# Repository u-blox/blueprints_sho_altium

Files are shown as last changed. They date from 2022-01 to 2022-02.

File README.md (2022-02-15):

# u-blox blueprints

This repository contains u-blox blueprints (reference designs) created using
Altium Designer.

There are two sets of files maintained within the blueprints_sho_altium
repository:
1. Designs
2. Chamber scans

## Designs
The designs folder contain the schematic and PCB design files for u-blox blueprint
reference designs. See the README.md within the Designs folder for the most
current list.

## Chamber scans
The chamber scan folders contain far field 2D and 3D radiation pattern scans
for a blueprint or EVK. See the README.md within the Chamber scans folder for
viewing instructions.

The folder structure is arranged like this:
```
/--+---Designs (Altium design files)
   |   |
   |   +--- Bxxx
   |   +--- Byyy
   |   +--- Bzzz
   |   ...
   |
   +---Chamber scans
       |
       +--- Bxxx
       +--- Byyy
       +--- Bzzz
       +--- EVK-abcd

... where "Bxxx", "Byyy", etc. are the blueprint numbers and "EVK-abcd" is the 
EVK board name.
```

---------------------------------------------------------------------------------
Copyright © u-blox

u-blox reserves all rights in this deliverable (documentation, software, etc.,
hereafter “Deliverable”).

u-blox grants you the right to use, copy, modify and distribute the Deliverable
provided hereunder for any purpose without fee.

THIS DELIVERABLE IS BEING PROVIDED "AS IS", WITHOUT ANY EXPRESS OR IMPLIED
WARRANTY. IN PARTICULAR, NEITHER THE AUTHOR NOR U-BLOX MAKES ANY REPRESENTATION
OR WARRANTY OF ANY KIND CONCERNING THE MERCHANTABILITY OF THIS DELIVERABLE
OR ITS FITNESS FOR ANY PARTICULAR PURPOSE.

In case you provide us a feedback or make a contribution in the form of a
further development of the Deliverable (“Contribution”), u-blox will have the
same rights as granted to you, namely to use, copy, modify and distribute the
Contribution provided to us for any purpose without fee.

---------------------------------------------------------------------------------

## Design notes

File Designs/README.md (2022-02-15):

# u-blox blueprint design files.

The designs contained within this repository are u-blox blueprints created with
Altium Designer. These are example designs suitable for a starting point in an
end-product. These are not full EVKs, rather an example of a feature used in a
project.

The following blueprints are maintained here:

|Blueprint number | Description |
|---|---|
| B212 | RF range test board, 40x22 plane, ANNA-B112 in corner position |
| B213 | RF range test board, 22x20 plane, ANNA-B112 in corner position |
| B214 | RF range test board, 40x22 plane, ANNA-B112 in edge position |
| B215 | RF range test board, 22x20 plane, ANNA-B112 in edge position |
| B216 | RF range test board, 40x22 plane, BMD-300, BMD-330, or BMD-360 |
| B217 | RF range test board, 22x20 plane, BMD-300, BMD-330, or BMD-360 |
| B218 | RF range test board, 40x22 plane, BMD-340 |
| B219 | RF range test board, 22x20 plane, BMD-340 |
| B220 | RF range test board, 40x22 plane, BMD-350 |
| B221 | RF range test board, 22x20 plane, BMD-350 |
| B222 | RF range test board, 40x22 plane, BMD-380 |
| B223 | RF range test board, 22x20 plane, BMD-380 |
| B224 | RF range test board, 40x22 plane, NINA-B112 |
| B225 | RF range test board, 22x20 plane, NINA-B112 |
| B226 | RF range test board, 40x22 plane, NINA-B302 |
| B227 | RF range test board, 22x20 plane, NINA-B302 |
| B228 | RF range test board, 40x22 plane, NINA-B306 |
| B229 | RF range test board, 22x20 plane, NINA-B306 |
| B230 | RF range test board, 40x22 plane, NINA-B406 |
| B231 | RF range test board, 22x20 plane, NINA-B406 |
| B232 | RF range test board, 40x22 plane, NORA-B106 |
| B233 | RF range test board, 22x20 plane, NORA-B106 |

Directory structure
---------------------------------------------------------------------------------
```
/-- Bxxx_name
    |
    +--- BOM
    |    |
    |    +--- Bxxx_name.xlsx = Bill of Materials output from Altium (optional)
    |
    +--- Documentation
    |    |
    |    +--- Bxxx_name.PDF = schematic in PDF format
    |
    +--- Fabrication
    |    |
    |    +--- Gerber = folder with Gerber file outputs
    |    +--- NC Drill = folder with drill data
    |    +--- ODB = folder with ODB file outputs
    |    +--- Pick Place = folder with pick and place tool outputs
    |    +--- Test Points = folder with test point outputs
    |
    +--- PCB
    |    |
    |    +--- Bxxx.PcbDoc = Altium PCB layout design file
    |
    +--- Settings
    |    |
    |    +--- Outputs.OutJob = Product output file definitions (BOM, PDF, fabrication, etc)
    |
    +--- Source
    |    |
    |    +--- Bxxx_.SchDoc = Altium schematic design file
    |
    +--- Bxxx_name.IntLib = integrated library of components used within the design
    +--- Bxxx_name.PrjPcb = Altium project file
    +--- Bxxx_name.PrjPcbVariants = Build variant definitions (optional)

```
The main files to view the design in Altium are the .PrjPcb, .SchDoc, .PcbDoc, and .IntLib.
B216 and B217 each have three variants, one each for BMD-300, BMD-330, and BMD-360 modules.
Other boards only have one variant, so the ".PcbDocVariants" file may not be present.

The other files are generated by Altium, and are provided here for user convenience.

---------------------------------------------------------------------------------
Copyright © u-blox

u-blox reserves all rights in this deliverable (documentation, software, etc.,
hereafter “Deliverable”).

u-blox grants you the right to use, copy, modify and distribute the Deliverable
provided hereunder for any purpose without fee.

THIS DELIVERABLE IS BEING PROVIDED "AS IS", WITHOUT ANY EXPRESS OR IMPLIED
WARRANTY. IN PARTICULAR, NEITHER THE AUTHOR NOR U-BLOX MAKES ANY REPRESENTATION
OR WARRANTY OF ANY KIND CONCERNING THE MERCHANTABILITY OF THIS DELIVERABLE
OR ITS FITNESS FOR ANY PARTICULAR PURPOSE.

In case you provide us a feedback or make a contribution in the form of a
further development of the Deliverable (“Contribution”), u-blox will have the
same rights as granted to you, namely to use, copy, modify and distribute the
Contribution provided to us for any purpose without fee.

---------------------------------------------------------------------------------

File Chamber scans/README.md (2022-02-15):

# EVK and blueprint - RF chamber scans

RF chamber scans are performed selected bluprint designs and EVKs. Blueprints
B212 through B233 correspond to "mid-size" (40 x 22 mm ground plane) and "small-
size" (22 x 20 mm ground plane) carrier boards for the module noted in the
filename and table below. In addition to the two blueprints for each module, 
EVKs were also scanned:

|Blueprint number | Description |
|---|---|
| B212 | RF range test board, 40x22 plane, ANNA-B112 in corner position |
| B213 | RF range test board, 22x20 plane, ANNA-B112 in corner position |
| B214 | RF range test board, 40x22 plane, ANNA-B112 in edge position |
| B215 | RF range test board, 22x20 plane, ANNA-B112 in edge position |
| B216 | RF range test board, 40x22 plane, BMD-300, BMD-330, or BMD-360 |
| B217 | RF range test board, 22x20 plane, BMD-300, BMD-330, or BMD-360 |
| B218 | RF range test board, 40x22 plane, BMD-340 |
| B219 | RF range test board, 22x20 plane, BMD-340 |
| B220 | RF range test board, 40x22 plane, BMD-350 |
| B221 | RF range test board, 22x20 plane, BMD-350 |
| B222 | RF range test board, 40x22 plane, BMD-380 |
| B223 | RF range test board, 22x20 plane, BMD-380 |
| B224 | RF range test board, 40x22 plane, NINA-B112 |
| B225 | RF range test board, 22x20 plane, NINA-B112 |
| B226 | RF range test board, 40x22 plane, NINA-B302 |
| B227 | RF range test board, 22x20 plane, NINA-B302 |
| B228 | RF range test board, 40x22 plane, NINA-B306 |
| B229 | RF range test board, 22x20 plane, NINA-B306 |
| B230 | RF range test board, 40x22 plane, NINA-B406 |
| B231 | RF range test board, 22x20 plane, NINA-B406 |
| B232 | RF range test board, 40x22 plane, NORA-B106 |
| B233 | RF range test board, 22x20 plane, NORA-B106 |
| EVK-ANNA-B112C  | ANNA-B112 EVK, SIP placed in the corner of the PCB |
| EVK-ANNA-B112E  | ANNA-B112 EVK, SIP placed along the PCB edge |
| EVK-ANNA-B112U  | ANNA-B112 EVK, external 3.2 dBi whip antenna |
| EVK-BMD-300-EVAL| BMD-300 EVK, PCB trace antenna |
| EVK-BMD-301-EVAL| BMD-301 EVK, external 5 dBi whip antenna |
| EVK-BMD-330-EVAL| BMD-330 EVK, PCB trace antenna |
| EVK-BMD-340-EVAL| BMD-340 EVK, PCB trace antenna |
| EVK-BMD-341-EVAL| BMD-341 EVK, external 3 dBi whip antenna |
| EVK-BMD-345-EVAL| BMD-345 EVK, external 3 dBi whip antenna |
| EVK-BMD-350-EVAL| BMD-350 EVK, PCB chip antenna |
| EVK-BMD-360-EVAL| BMD-360 EVK, PCB trace antenna |
| EVK-BMD-380-EVAL| BMD-380 EVK, PCB chip antenna | 
| EVK-NINA-B111 | NINA-B111, external 3.2 dBi whip antenna |
| EVK-NINA-B112 | NINA-B112, PIFA antenna |
| EVK-NINA-B301 | NINA-B301, external 3.2 dBi whip antenna |
| EVK-NINA-B302 | NINA-B302, PIFA antenna |
| EVK-NINA-B306 | NINA-B306, PCB trace antenna |
| EVK-NINA-B400 | NINA-B400, external 3.2 dBi whip antenna |
| EVK-NINA-B406 | NINA-B406, PCB trace antenna |
| EVK-NORA-B106 | NORA-B106, PCB trace antenna |

Unzip the selected file to a folder. 
Each folder contains four files and four similarly named sub-folders:
<board>-2d.html and <board>-2d-files folder
<board>-3d-xy.html and <board>-3d-xy-files folder
<board>-3d-xz.html and <board>-3d-xz-files folder
<board>-3d-yz.html and <board>-3d-yz-files folder

Open the HTML file in a web browser to view the plot.

The three 3D plots display the same data. The only difference is the initial 
view according to the plane in the filename. For example, <board>-3d-xy.html
shows the plot looking at the X-Y plane with the Z-axis "out of the page".
Hovering over a point on the 3D plot will show the measured EIRP, azimuth,
and elevation. Click and drag the plot to rotate it.

The 2D plots display slices of the 3D plot at the X-Y, X-Z, and Y-Z planes.
Hovering over the plot will show the EIRP, angle, and an indication of 
whether the horizontal or vertical antenna axis was used, or a combined 
measurement of the two.

Scans for all blueprints are in 15 degree azimuth and elevation increments. 
Additional scans for EVK-NINA-B302, EVK-NINA-B306, EVK-NINA-B406, 
EVK-BMD-340-EVAL, and EVK-BMD-380-EVAL, denoted by "-5deg" added to the filename

---------------------------------------------------------------------------------
Copyright © u-blox

u-blox reserves all rights in this deliverable (documentation, software, etc.,
hereafter “Deliverable”).

u-blox grants you the right to use, copy, modify and distribute the Deliverable
provided hereunder for any purpose without fee.

THIS DELIVERABLE IS BEING PROVIDED "AS IS", WITHOUT ANY EXPRESS OR IMPLIED
WARRANTY. IN PARTICULAR, NEITHER THE AUTHOR NOR U-BLOX MAKES ANY REPRESENTATION
OR WARRANTY OF ANY KIND CONCERNING THE MERCHANTABILITY OF THIS DELIVERABLE
OR ITS FITNESS FOR ANY PARTICULAR PURPOSE.

In case you provide us a feedback or make a contribution in the form of a
further development of the Deliverable (“Contribution”), u-blox will have the
same rights as granted to you, namely to use, copy, modify and distribute the
Contribution provided to us for any purpose without fee.

---------------------------------------------------------------------------------

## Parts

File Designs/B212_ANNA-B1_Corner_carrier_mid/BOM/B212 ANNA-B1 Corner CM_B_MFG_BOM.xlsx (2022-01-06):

Description | Designator | Footprint | Quantity | Manufacturer | Manufacturer P/N | Manufacturer Part Number
Chip Capacitor, 10 pF, +/- 5%, 50 V, 0402 (1005 Metric) | C1, C2 | CAPC1005X55X25ML05T05 | 2
CAP CER X5R 0402 | C3 | Cap 0402 | 1 | Samsung Electro-Mechanics | CL05A104KP5NNN
Diode, ESD9B, 3.3V, ST5G, SOD-923 | D1, D2 | SOD-923 | 2 | ON Semiconductor | ESD9B3.3ST5G
LED, RGB Diffused SMT, PLCC4 4 Pin | D3 | 4-PLCC | 1 | Cree, Inc. | CLMVB-FKA-CFHEHLCBB7a363
THT Angled Pin Header WR-PHD, Pitch 2.54 mm, Single Row, 8 pins | P1 | 61300811021 | 1 | Wurth Electronics |  | 61300811021
Resistor, 499ohm, 1%, 1/16W, 0402 | R1 | RES 0402 HD | 1 | Rohm Semiconductor | MCR01MRTF4990
Resistor, 220ohm, 5%, 1/16W, 0402. | R2, R3 | RES 0402 HD | 2 | Panasonic Electronic Components | ERJ-2GEJ221X
Button, Momentary SPST-NO, 0.05A, 12V, 3mm x 2.5mm | SW1, SW2 | B3U-1000P | 2 | Omron Electronics Inc-EMC Div | B3U-1000P
u-blox ANNA-B112 Bluetooth 5 LE module | U1 | ANNA_LGA52S_650X650 | 1 | u-blox
XTAL, 2Pin, 32.768kHz, 7pF 20ppm | X1 | XTAL_3215 | 1 | Epson | FC-135 32.7680KA-AG3

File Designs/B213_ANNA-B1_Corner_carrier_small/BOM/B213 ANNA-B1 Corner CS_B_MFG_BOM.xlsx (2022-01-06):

Description | Designator | Footprint | Quantity | Manufacturer | Manufacturer P/N | Manufacturer Part Number
Chip Capacitor, 10 pF, +/- 5%, 50 V, 0402 (1005 Metric) | C1, C2 | CAPC1005X55X25ML05T05 | 2
Diode, ESD9B, 3.3V, ST5G, SOD-923 | D1, D2 | SOD-923 | 2 | ON Semiconductor | ESD9B3.3ST5G
LED, RGB Diffused SMT, PLCC4 4 Pin | D3 | 4-PLCC | 1 | Cree, Inc. | CLMVB-FKA-CFHEHLCBB7a363
Chip Inductor, 56 nH, +/-5%, 390 mA, -55 to 125 degC, 0603 (1608 Metric), RoHS, Tape and Reel | L1, L2 | INDC1608X100X30LL20T10 | 2 | Murata
1.5M screw mounting hole, plated | MH1, MH2 | MH_M1.5 | 2
THT Angled Pin Header WR-PHD, Pitch 2.54 mm, Single Row, 8 pins | P1 | 61300811021 | 1 | Wurth Elektronik |  | 61300811021
CON PADS FOR CBL PLUG-OF-NAILS 6-PIN NO LEGS | P2 | TC2030-IDC-NL | 1 | TAG Connect | TC2030-IDC-NL
Resistor, 220ohm, 5%, 1/16W, 0402. | R4 | RES 0402 HD | 1
Resistor, 220ohm, 5%, 1/16W, 0402. | R5, R6, R7, R8, R9, R10, R11, R12, R13, R14, R15, R17 | RES 0402 HD | 12 | [NoParam], Panasonic Electronic Components | [NoParam], ERJ-2GEJ221X
Resistor, 499ohm, 1%, 1/16W, 0402 | R16 | RES 0402 HD | 1 | Rohm Semiconductor | MCR01MRTF4990
Button, Momentary SPST-NO, 0.05A, 12V, 3mm x 2.5mm | SW1, SW2 | B3U-1000P | 2 | Omron Electronics Inc-EMC Div | B3U-1000P
u-blox ANNA-B112 Bluetooth 5 LE module | U1 | ANNA_LGA52S_650X650 | 1 | u-blox
XTAL, 2Pin, 32.768kHz, 7pF 20ppm | X1 | XTAL_3215 | 1 | Epson | FC-135 32.7680KA-AG3

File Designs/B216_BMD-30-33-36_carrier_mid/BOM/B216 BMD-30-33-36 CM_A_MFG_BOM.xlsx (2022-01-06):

Description | Designator | Footprint | Quantity | Manufacturer | Manufacturer P/N | Manufacturer Part Number
CAP CER COG 0402 | C1, C2 | Cap 0402 | 2 | Murata Manufacturing Company, Ltd. | GRM1555C1H120KZ01
CAP CER COG 0402 | C3, C4 | Cap 0402 | 2 | Murata Manufacturing Company, Ltd. | GRM1555C1H100CZ01
CAP CER X5R 0402 | C5 | Cap 0402 | 1 | Samsung Electro-Mechanics | CL05A104KP5NNN
LED, RGB Diffused SMT, PLCC4 4 Pin | D1 | 4-PLCC | 1 | Cree, Inc. | CLMVB-FKA-CFHEHLCBB7a363
Diode, ESD9B, 3.3V, ST5G, SOD-923 | D2, D3 | SOD-923 | 2 | ON Semiconductor | ESD9B3.3ST5G
1.5M screw mounting hole, plated | MH1, MH2 | MH_M1.5 | 2
CON PADS FOR CBL PLUG-OF-NAILS 6-PIN NO LEGS | P1 | TC2030-IDC-NL | 1 | TAG Connect | TC2030-IDC-NL
THT Angled Pin Header WR-PHD, Pitch 2.54 mm, Single Row, 8 pins | P2 | 61300811021 | 1 | Wurth Electronics |  | 61300811021
Resistor, 499ohm, 1%, 1/16W, 0402 | R1 | RES 0402 HD | 1 | Rohm Semiconductor | MCR01MRTF4990
Resistor, 220ohm, 5%, 1/16W, 0402. | R2, R3 | RES 0402 HD | 2 | Panasonic Electronic Components | ERJ-2GEJ221X
Button, Momentary SPST-NO, 0.05A, 12V, 3mm x 2.5mm | SW1, SW2 | B3U-1000P | 2 | Omron Electronics Inc-EMC Div | B3U-1000P
u-blox BMD-300 Bluetooth 5 LE module | U1 | BMD_LGA47S_1400X980X190_PCB | 1 | u-blox | BMD-300-A-R
XTAL, 2Pin, 32.768kHz, 7pF 20ppm | X1 | XTAL_3215 | 1 | Epson | FC-135 32.7680KA-AG3

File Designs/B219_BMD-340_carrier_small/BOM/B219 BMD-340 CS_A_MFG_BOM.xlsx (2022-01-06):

Description | Designator | Footprint | Quantity | Manufacturer | Manufacturer P/N | Manufacturer Part Number
CAP CER COG 0402 | C1, C2 | Cap 0402 | 2 | Murata Manufacturing Company, Ltd. | GRM1555C1H100CZ01
CAP CER X5R 0402 | C3, C4 | Cap 0402 | 2 | Samsung Electro-Mechanics | CL05A104KP5NNN
Diode, ESD9B, 3.3V, ST5G, SOD-923 | D1, D2 | SOD-923 | 2 | ON Semiconductor | ESD9B3.3ST5G
LED, RGB Diffused SMT, PLCC4 4 Pin | D3 | 4-PLCC | 1 | Cree, Inc. | CLMVB-FKA-CFHEHLCBB7a363
Chip Inductor, 22 nH, +/-5%, 640 mA, -55 to 125 degC, 0603 (1608 Metric), RoHS, Tape and Reel | L1, L2 | INDC1608X100X30LL20T10 | 2 | Murata
1.5M screw mounting hole, plated | MH1, MH2 | MH_M1.5 | 2
CON PADS FOR CBL PLUG-OF-NAILS 6-PIN NO LEGS | P1 | TC2030-IDC-NL | 1 | TAG Connect | TC2030-IDC-NL
THT Angled Pin Header WR-PHD, Pitch 2.54 mm, Single Row, 8 pins | P2 | 61300811021 | 1 | Wurth Electronics |  | 61300811021
RES THICK FILM CHIP 0402 | R1, R2, R3, R7, R8, R9, R10, R11, R12, R13, R14 | RES 0402 HD | 11 | YAGEO | 2322_705_87221_L
Resistor, 499ohm, 1%, 1/16W, 0402 | R4 | RES 0402 HD | 1 | Rohm Semiconductor | MCR01MRTF4990
Resistor, 220ohm, 5%, 1/16W, 0402. | R5, R6 | RES 0402 HD | 2 | Panasonic Electronic Components | ERJ-2GEJ221X
Button, Momentary SPST-NO, 0.05A, 12V, 3mm x 2.5mm | SW1, SW2 | B3U-1000P | 2 | Omron Electronics Inc-EMC Div | B3U-1000P
u-blox BMD-340 Bluetooth 5 LE, 802.15.4 module | U1 | BMD_LGA68S_1500X1020X190_PCB | 1 | u-blox | BMD-340-A-R
XTAL, 2Pin, 32.768kHz, 7pF 20ppm | X1 | XTAL_3215 | 1 | Epson | FC-135 32.7680KA-AG3

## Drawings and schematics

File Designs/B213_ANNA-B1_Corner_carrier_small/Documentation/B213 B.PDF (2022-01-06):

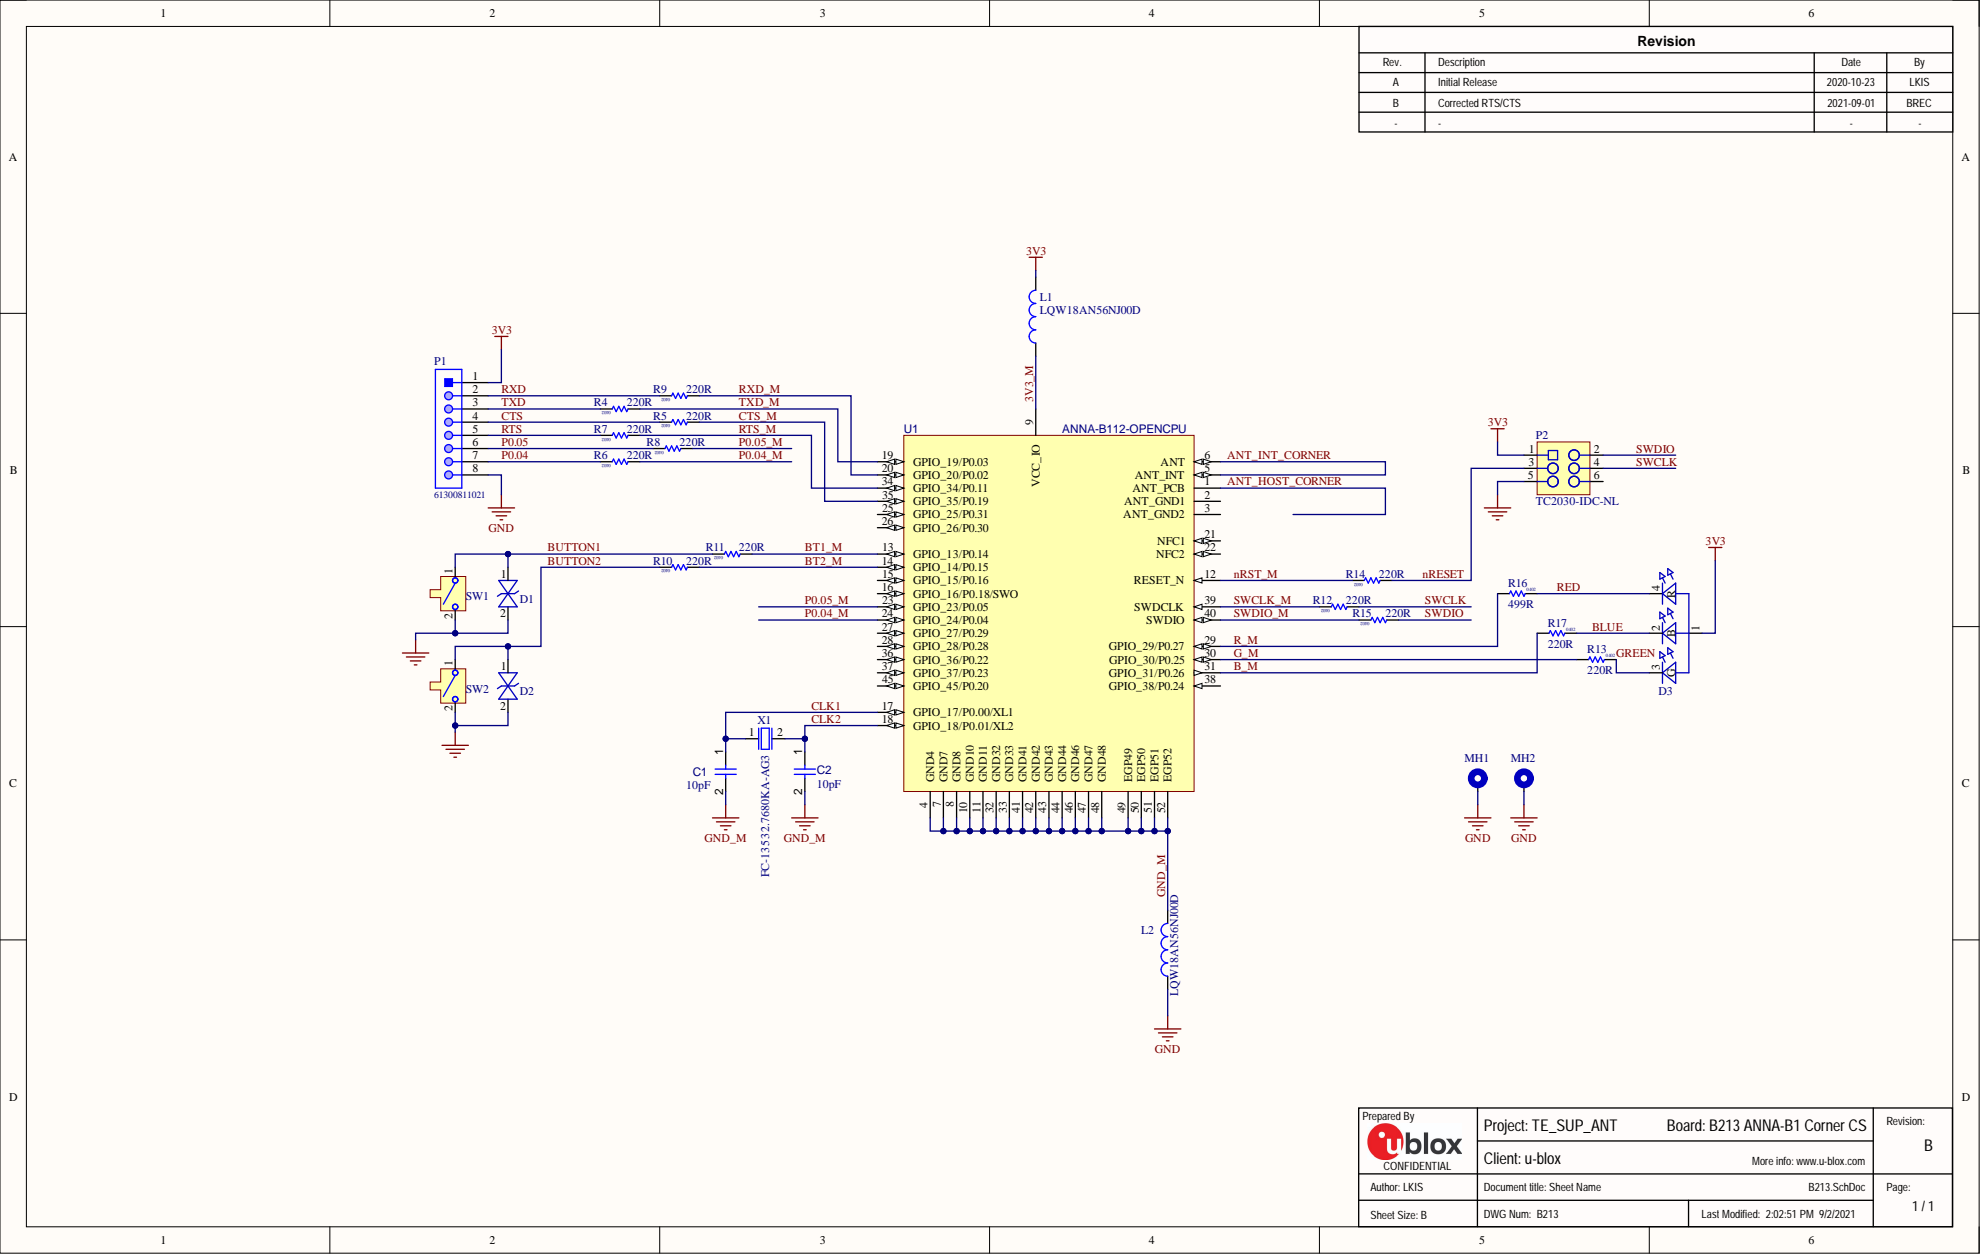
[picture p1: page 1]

Rev. | Description | Date | By
A | Initial Release | 2020-10-23 | LKIS

B | Corrected RTS/CTS | 2021-09-01 | BREC

BUTTON2 R10

P0.05_M | GPIO_16/P0.18/SWO 16 GPIO_15/P0.16 15

GPIO_36/P0.22 36 | G_M
GPIO_37/P0.23 37 | B_M

Board: B213 ANNA-B1 Corner CS

More info: www.u-blox.com

Author: LKIS | Document title: Sheet Name B213.SchDoc | Page: 1 / 1

Sheet Size: B | DWG Num: B213 | Last Modified: 2:02:51 PM 9/2/2021

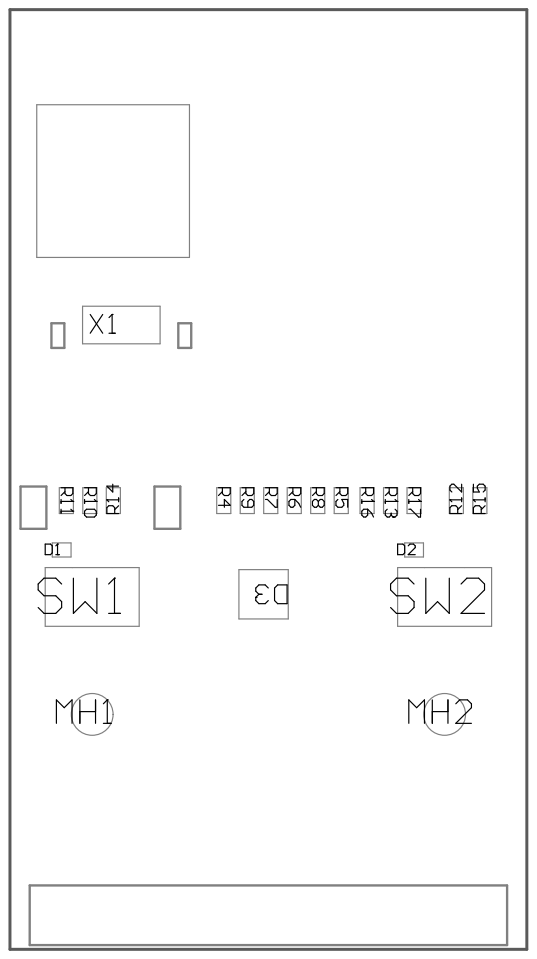
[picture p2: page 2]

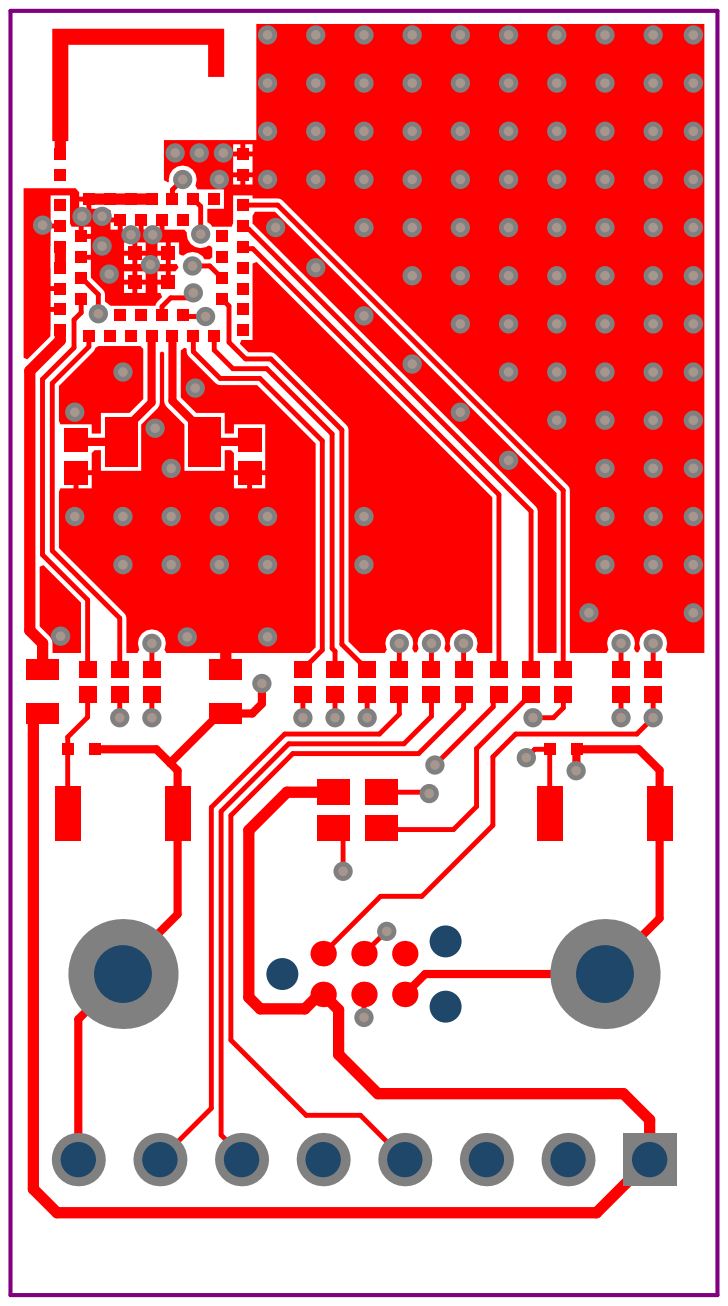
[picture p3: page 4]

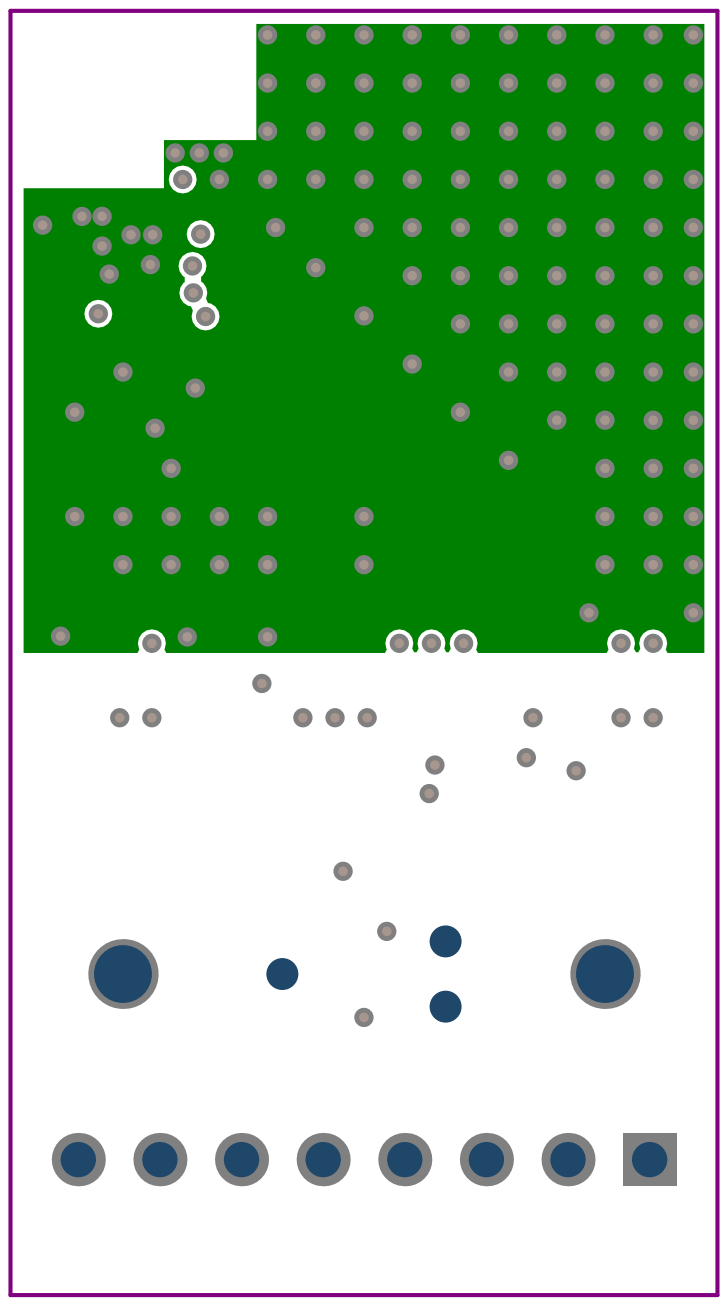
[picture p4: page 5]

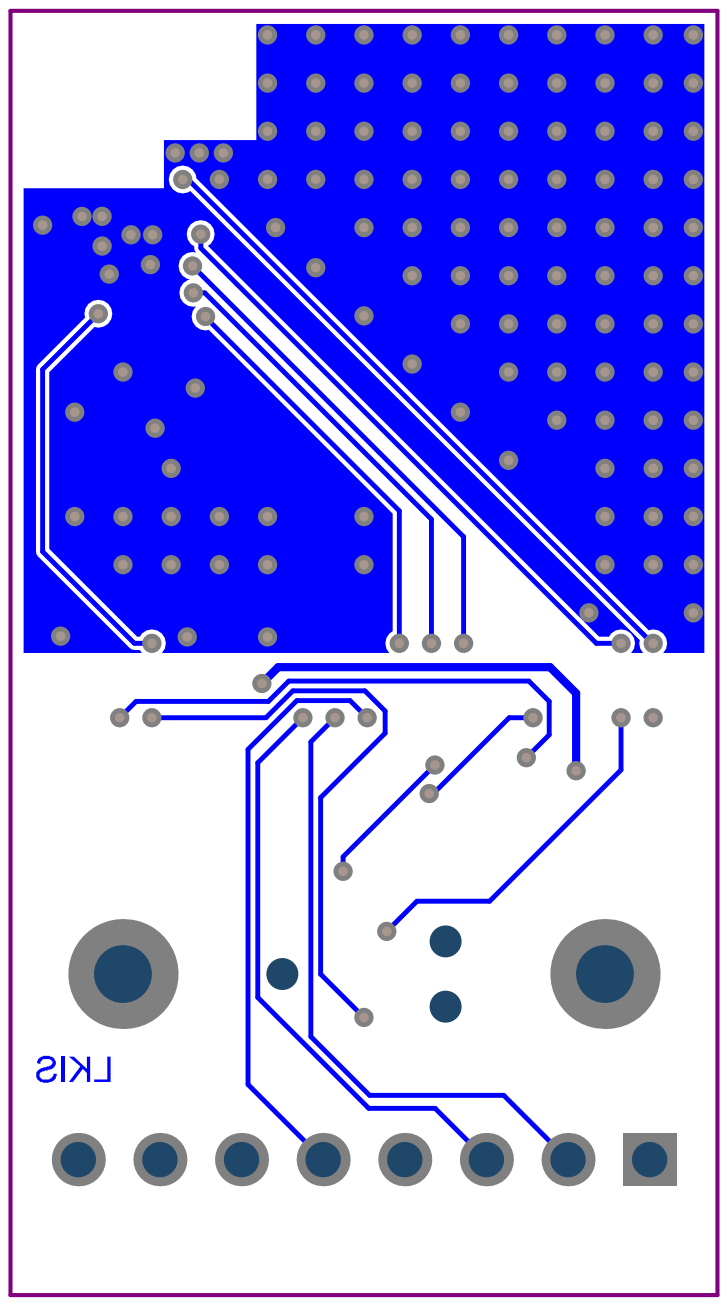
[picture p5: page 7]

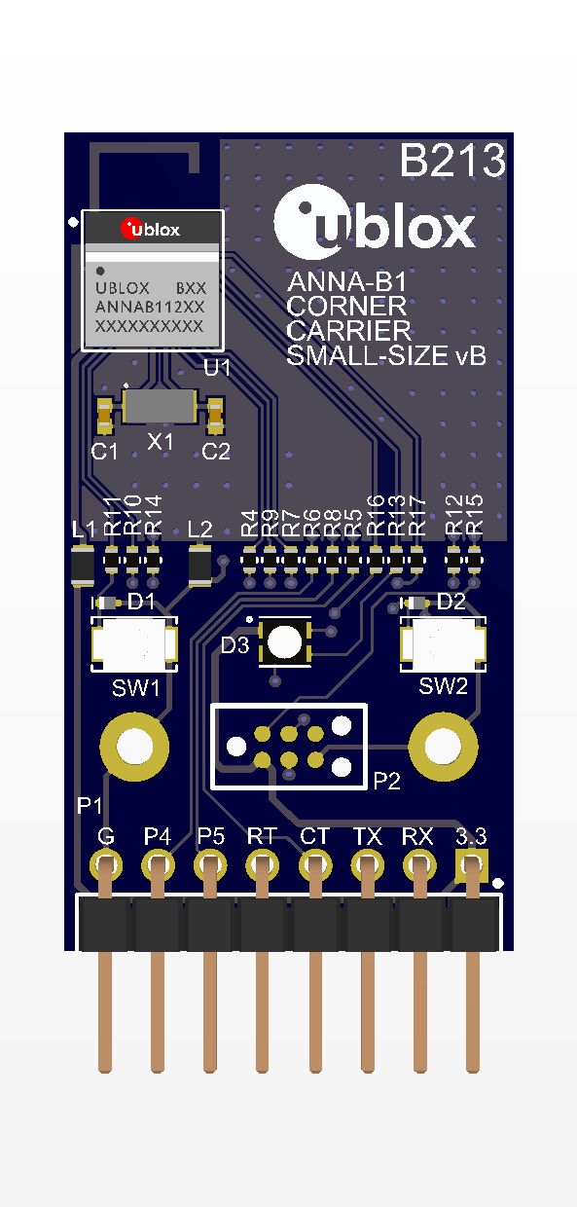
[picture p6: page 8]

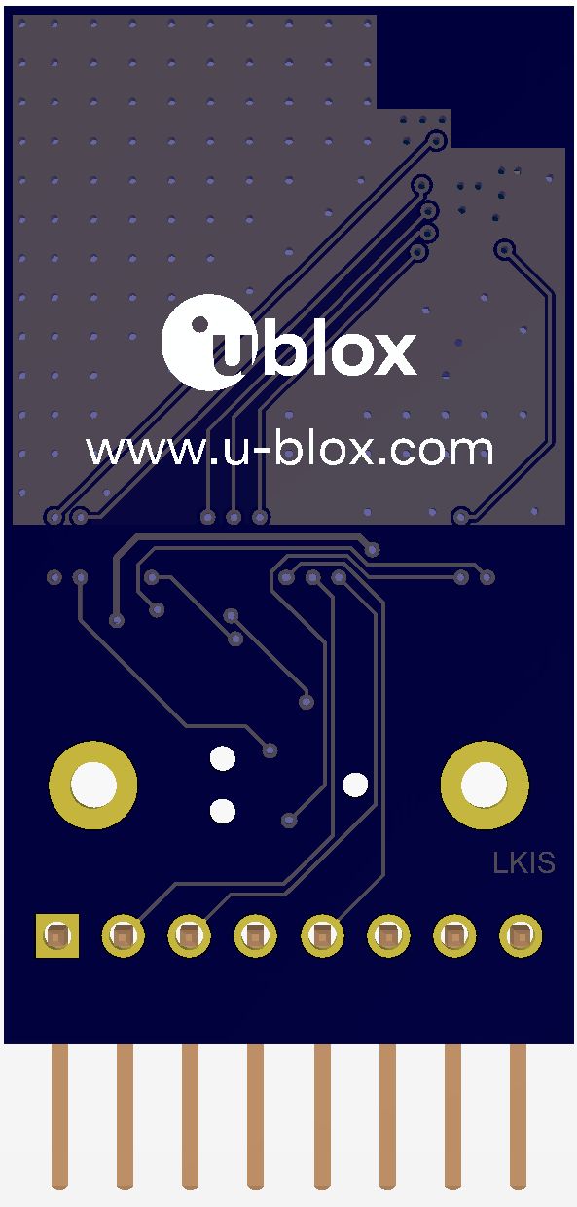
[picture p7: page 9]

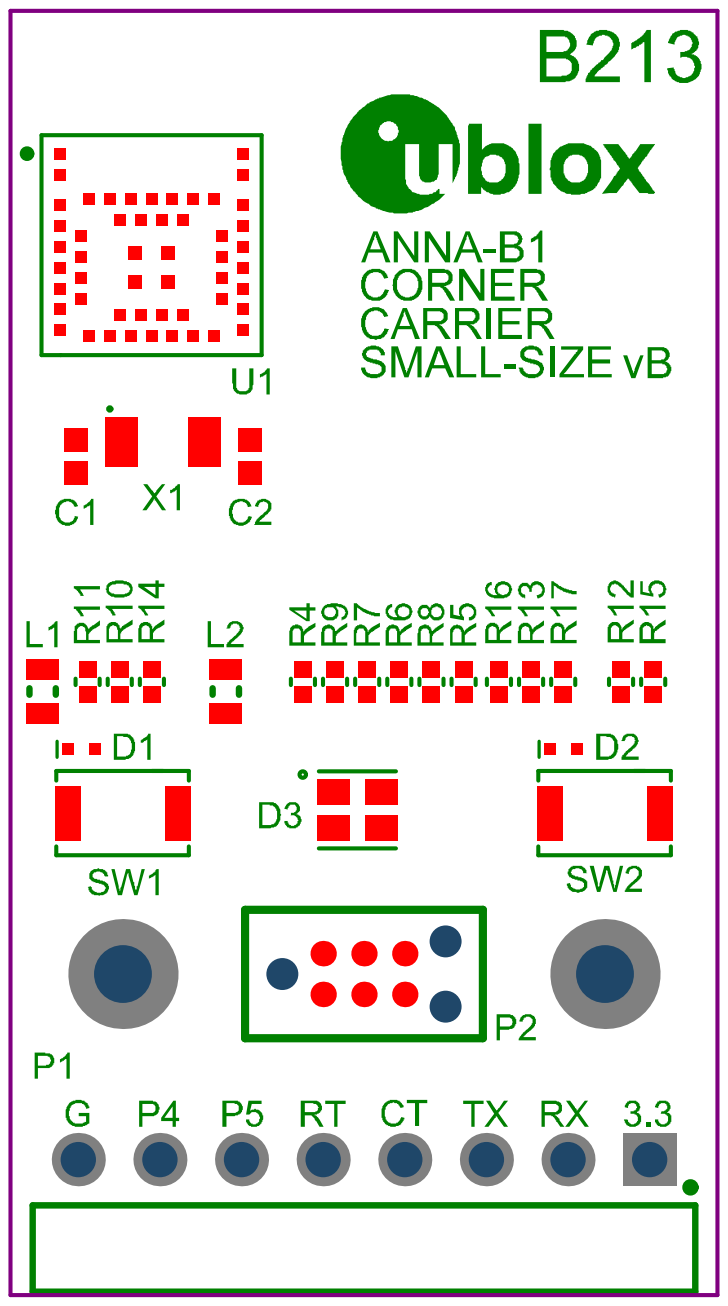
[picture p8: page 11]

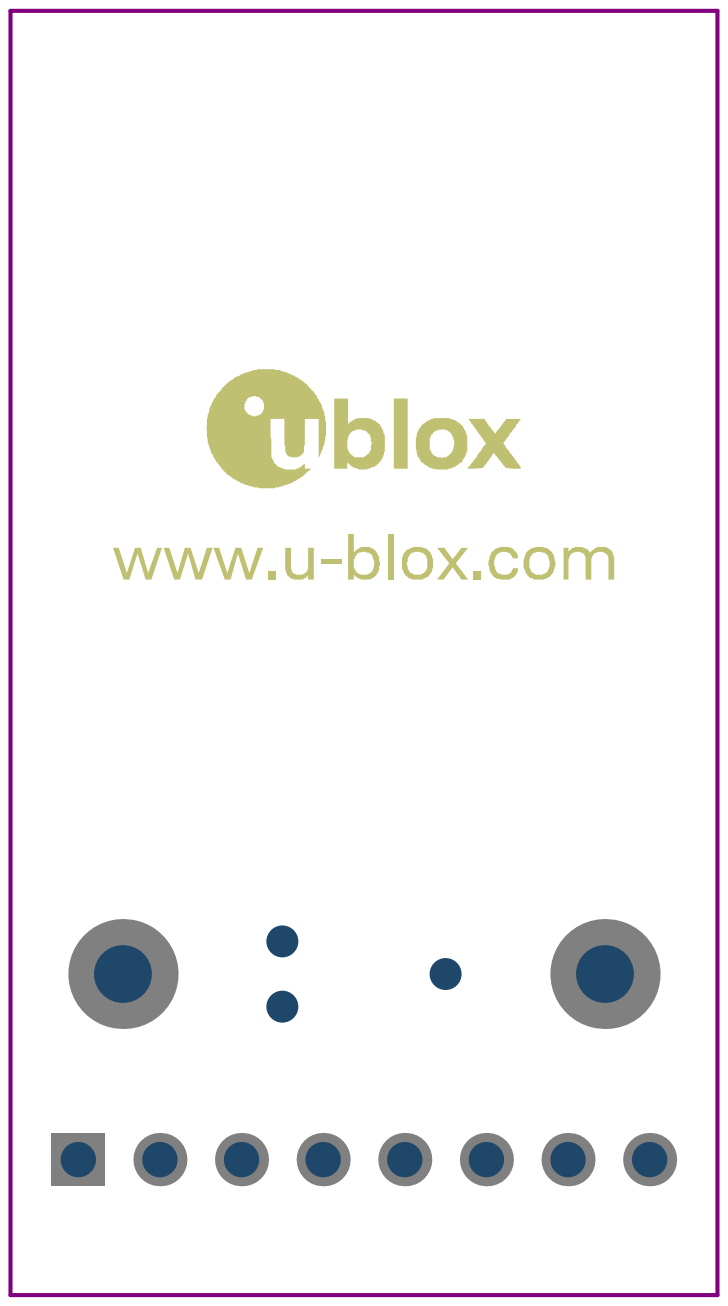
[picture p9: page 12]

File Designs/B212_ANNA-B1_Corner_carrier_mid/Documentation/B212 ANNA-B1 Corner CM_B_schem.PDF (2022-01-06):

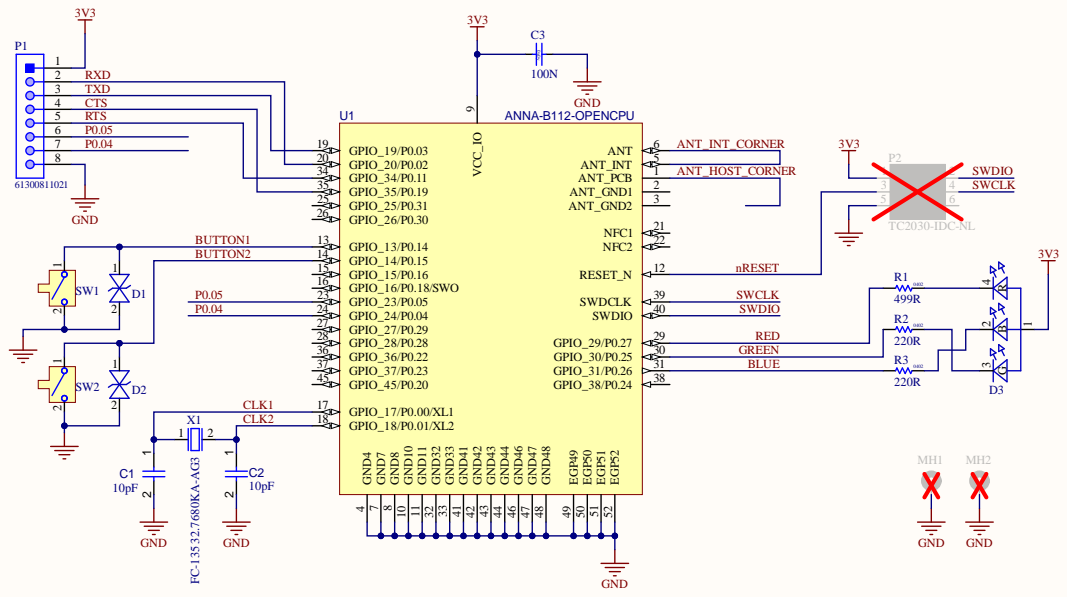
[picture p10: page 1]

Rev. | Description | Date | By
A | Initial Release | 2020-10-23 | LKIS

B | Corrected RTS/CTS | 2021-09-01 | BREC

CT S
RT S

2 0 | | 5
3 4 | | 1 A N T _ H OST _ C O RN

BU T T O N 2 | 1 4 | 1 2
1 5 P0 . 0 5

Board: B212 ANNA-B1 Corner CM

More info: www.u-blox.com

Author: LKIS | Document title: Sheet Name B212.SchDoc | Page: 1 / 1

Sheet Si ze: B | DWG Num: B212 | Last Modified: 10:53:07 AM 9/2/2021

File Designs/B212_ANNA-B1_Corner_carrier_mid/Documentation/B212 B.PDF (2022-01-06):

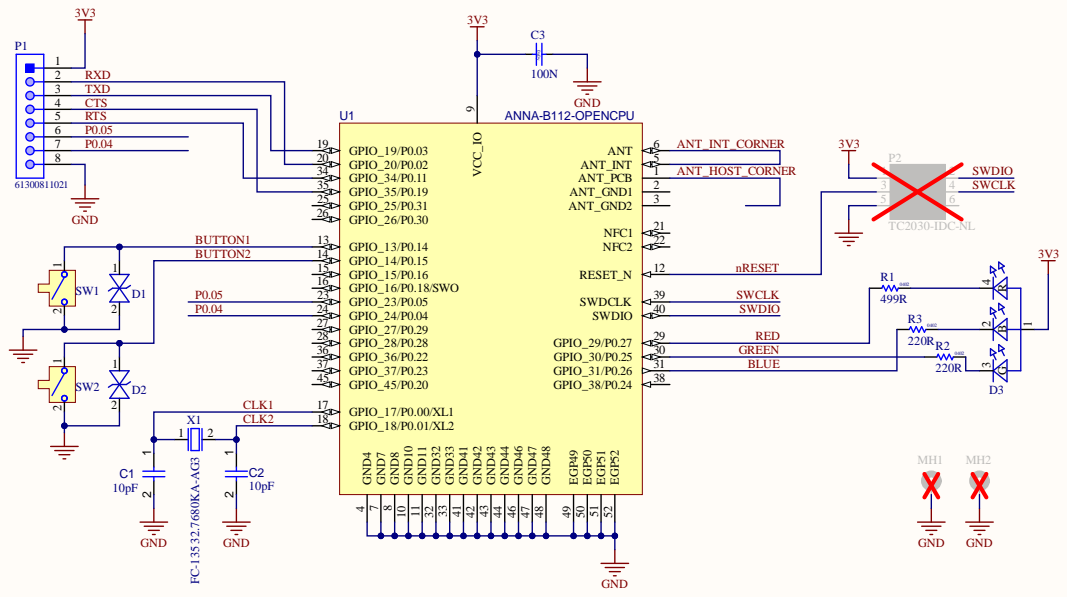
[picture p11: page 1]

Rev . | Des cription | Date | By
A | Initial Releas e | 2020-10-23 | LKIS

B | Corrected RTS/CTS | 2021-09-01 | BREC

CT S
RT S

2 0 | | 5
3 4 | | 1 A N T _ H OST _ C O RN

BU T T O N 2 | 1 4 | 1 2
1 5 P0 . 0 5

Board: B212 ANNA-B1 Corner CM

More info: www.u-blox.com

Author: LKIS | Document title: Sheet Name B212.SchDoc | Page: 1 / 1

Sheet Si ze: B | DWG Num: B212 | Last Modified: 2:02:04 PM 9/2/2021

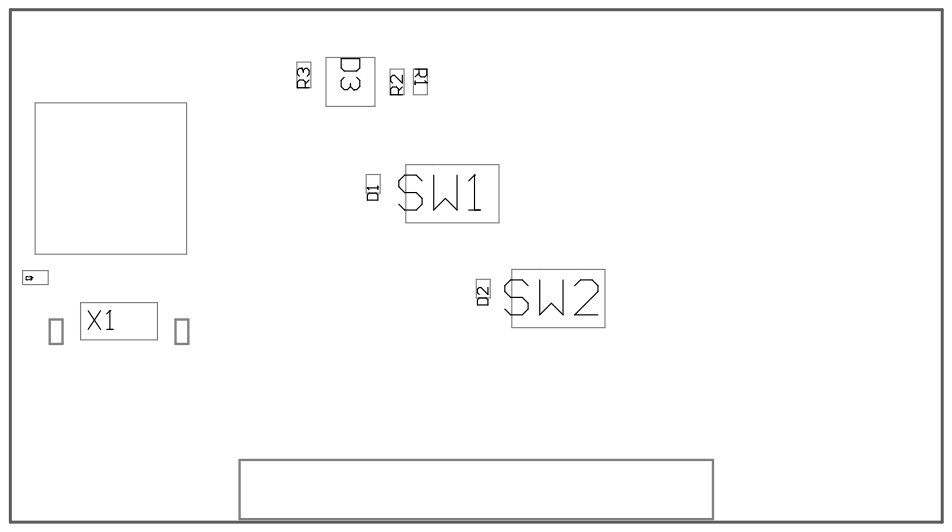
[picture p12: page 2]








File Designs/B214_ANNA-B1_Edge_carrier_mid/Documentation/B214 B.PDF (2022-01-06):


Rev . | Des cription | Date | By
A | Initial Releas e | 2020-10-23 | LKIS

B | Corrected RTS/CTS | 2021-09-01 | BREC

CT S
RT S

2 0 | | 5
3 4 | | 1
3 5 | | 2 3

3 | nRE S E T | 5

BU T T O N 2 | 1 4 | 1 2
1 5 P0 . 0 5

Board: B214 ANNA-B1 Edge CM

More info: www.u-blox.com

Author: LKIS | Document title: Sheet Name B214.SchDoc | Page: 1 / 1

Sheet Si ze: B | DWG Num: B214 | Last Modified: 2:03:26 PM 9/2/2021









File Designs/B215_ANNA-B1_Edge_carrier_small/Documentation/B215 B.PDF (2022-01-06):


Rev. | Description | Date | By
A | Initial Release | 2020-10-23 | LKIS

B | Corrected RTS/CTS | 2021-09-02 | BREC

P0.05_M | GPIO_16/P0.18/SWO 16 GPIO_15/P0.16 15

SWCLK_M 220R 2040 R12 SWCLK SWDIO_M 220R 2040 R15 SWDIO

Board: B215 ANNA-B1 Edge CS

More info: www.u-blox.com

Author: LKIS | Document title: Sheet Name B215.SchDoc | Page: 1 / 1

Sheet Size: B | DWG Num: B215 | Last Modified: 2:03:59 PM 9/2/2021









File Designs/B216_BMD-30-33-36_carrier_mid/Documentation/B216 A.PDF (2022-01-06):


Rev. | Description | Date | By
A | Initial Release | 2020-10-23 | BREC

P0.27 8 | RED

P0.29/AIN5 10 | GREEN
P0.30/AIN6 11 | BLUE

P0.02/AIN0 15 | BUTTON_2

3 | TXD
4 | CTS
5 | RTS
6 | P0.04
7 | P0.03

More info: www.u-blox.com

Author: BREC | Document title: Sheet Name B216.SchDoc | Page: 1 / 1

Sheet Size: B | DWG Num: B216 | Last Modified: 5:29:12 PM 9/2/2021









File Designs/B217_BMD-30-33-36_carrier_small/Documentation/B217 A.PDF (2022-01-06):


Rev. | Description | Date | By
A | Initial Release | 2020-10-23 | BREC

3 | TXD
4 | CTS
5 | RTS
6 | P0.04
7 | P0.03

More info: www.u-blox.com

Author: BREC | Document title: Sheet Name B217.SchDoc | Page: 1 / 1

Sheet Size: B | DWG Num: B217 | Last Modified: 5:32:21 PM 9/2/2021









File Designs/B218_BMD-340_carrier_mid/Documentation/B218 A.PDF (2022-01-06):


Rev. | Description | Date | By
A | Initial Release | 2020-10-19 | BREC

P0.27 8 | RED

P0.29/AIN5 10 | GREEN
P0.30/AIN6 11 | BLUE

P0.02/AIN0 15 | BUTTON_2

3 | TXD
4 | CTS
5 | RTS
6 | P0.04
7 | P0.03

More info: www.u-blox.com

Author: BREC | Document title: Sheet Name B218.SchDoc | Page: 1 / 1

Sheet Size: B | DWG Num: B218 | Last Modified: 5:35:07 PM 9/2/2021









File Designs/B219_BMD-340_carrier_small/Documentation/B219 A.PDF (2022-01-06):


Rev. | Description | Date | By
A | Initial Release | 2020-10-23 | BREC

GND_M 3V3

4 | CTS
5 | RTS
6 | P0.04
7 | P0.03

More info: www.u-blox.com

Author: BREC | Document title: Sheet Name B219.SchDoc | Page: 1 / 1

Sheet Size: B | DWG Num: B219 | Last Modified: 5:37:58 PM 9/2/2021









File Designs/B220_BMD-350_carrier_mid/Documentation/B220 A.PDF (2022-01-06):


Rev. | Description | Date | By
A | Initial Release | 2020-10-23 | BREC

P0.27 32 | RED

GREEN

P0.30/AIN6 29 | BLUE

P0.02/AIN0 28 | BUTTON_2

3 | TXD
4 | CTS
5 | RTS
6 | P0.04
7 | P0.03

More info: www.u-blox.com

Author: BREC | Document title: Sheet Name B220.SchDoc | Page: 1 / 1

Sheet Size: B | DWG Num: B220 | Last Modified: 5:47:44 PM 9/2/2021









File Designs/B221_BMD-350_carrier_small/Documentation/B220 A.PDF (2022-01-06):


Rev. | Description | Date | By
A | Initial Release | 2020-10-23 | BREC

3 | TXD
4 | CTS
5 | RTS
6 | P0.04
7 | P0.03

More info: www.u-blox.com

Author: BREC | Document title: Sheet Name B221.SchDoc | Page: 1 / 1

Sheet Size: B | DWG Num: B221 | Last Modified: 5:58:02 PM 9/2/2021









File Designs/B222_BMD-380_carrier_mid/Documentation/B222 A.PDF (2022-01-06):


Rev. | Description | Date | By
A | Initial Release | 2020-10-23 | BREC

P0.27 32 | RED

P0.29/AIN5 37 | GREEN
P0.30/AIN6 42 | BLUE

P0.02/AIN0 41 | BUTTON_2

3 | TXD
4 | CTS
5 | RTS
6 | P0.04
7 | P0.03

More info: www.u-blox.com

Author: BREC | Document title: Sheet Name B222.SchDoc | Page: 1 / 1

Sheet Size: B | DWG Num: B222 | Last Modified: 6:00:29 PM 9/2/2021









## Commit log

2021-11-16 Add B212
    [B212 ANNA-B1 Corner CM_B_MFG_BOM.xlsx, B212.PcbDoc, B212.SchDoc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]
2021-11-16 Edit chamber scan readme
2022-01-06 Added all antenna project bluprints and chamber scans
    [B212 ANNA-B1 Corner CM_B_MFG_BOM.xlsx, B212.PcbDoc, B212.SchDoc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]
